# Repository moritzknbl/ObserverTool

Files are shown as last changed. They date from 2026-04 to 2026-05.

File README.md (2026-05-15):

# OpenCirclz - ObserverTool

A smart, pocket-sized timing and utility device for Roundnet observers, built on the ESP32 platform. It features timers for every situation with haptic feedback, a coin toss generator, seamless Scoreboard synchronization, and built-in OTA (Over-The-Air) update capabilities.

## ✨ Features
* **Smart Timers:** Pre-configured programs (Serve, Timeout, Break, Medicals) with visual countdowns.
* **Scoreboard Integration:** Wirelessly broadcasts active timers to the OpenCirclz Scoreboard via ESP-NOW for live stream or crowd overlays.
* **Haptic Feedback:** Custom vibration profiles for warnings, alarms, and interactions for a look-free interaction.
* **Power Management:** Auto-dimming and sleep modes for maximum battery life.
* **Coin Toss:** Built-in random heads/tails generator.
* **OTA & Web Hub:** Secret service mode to flash new firmware via Wi-Fi without a cable, and a Web Hub to configure hardware settings directly from your smartphone.
* **Easter Egg:** Hidden "Flappy Dot" mini-game.

## 🛠️ Hardware Requirements
* **Microcontroller:** ESP32-C3 Super Mini [HERE](https://de.aliexpress.com/item/1005008796274949.html)
* **Display:** 0.96" OLED I2C (128x64, SSD1306) [HERE](https://de.aliexpress.com/item/1005007084725556.html)
* **Inputs:** 2x Push Buttons (Start & Mode) (12*11mm opening size) [HERE](https://de.aliexpress.com/item/1005009402689922.html)
  *(Note: The software defaults to Normally Closed (NC) buttons, but Normally Open (NO) is fully supported and easily configurable via the Web Hub or local Settings Menu).*
* **Vibration:** QYF-740 Vibration Motor Module (Built-in driver, operates at 3.0-5.3VDC) [HERE](https://aliexpress.com/item/1005009127931477.html)
* **Battery:** Small 502030 3.7V LiPo Battery [HERE](https://de.aliexpress.com/item/1005006584143607.html)
* **Power Switch**: Simple ON/OFF Power Switch (19*13mm opening size) [HERE](https://aliexpress.com/item/1005008276122557.html)
* **Charge Controller:** Mini Type-C LiPo Charge/Discharge Module *(Specs: 18x12mm, 5V to 4.2V, set to 0.1A charge current, integrated over-discharge protection)* [HERE](https://de.aliexpress.com/item/1005010413122149.html)

### Pin Configuration
| Component | ESP32 Pin |
|---|---|
| I2C SCL (OLED) | GPIO 6 |
| I2C SDA (OLED) | GPIO 7 |
| START Button | GPIO 3 |
| MODE Button | GPIO 4 |
| Vibration Motor | GPIO 10 |

*(Note: Buttons are configured as `INPUT_PULLUP`, so connect them between the GPIO and GND).*

## 🧊 3D Printed Enclosure
To complete your ObserverTool, a custom-designed 3D printable case is available. You can find all the necessary `.stl` files directly in the [enclosure](enclosure) folder. 

**Assembly & Design:**
* **Highly Maintenance-Friendly:** The entire enclosure is designed without the need for any glue. 
* **Hardware:** Everything is assembled using **1.7 x 5 mm screws**.
* **Smart Mounting:** The OLED display, ESP32, and battery are securely held in place using custom 3D-printed pressure plates. This makes future repairs or battery replacements incredibly easy.

**Recommended Print Settings:**
* **Material:** PLA, PETG
* **Infill:** 15-20% is usually sufficient.

## 💻 Software Dependencies
To compile this project in the Arduino IDE or PlatformIO, you need the following libraries:
* `Adafruit GFX Library`
* `Adafruit SSD1306`

The ESP32 core libraries (`WiFi`, `esp_now`, `esp_wifi`, `WebServer`, `Update`, `DNSServer`, `Preferences`) are included by default in the ESP32 board package.

## 📥 Installation & Flashing Guide (Arduino IDE)

Follow these steps to compile and flash the firmware to your ESP32 for the first time:

### 1. Setup Arduino IDE & ESP32 Core
1. Download and install the latest [Arduino IDE](https://www.arduino.cc/en/software).
2. Open the IDE, go to **File > Preferences**, and paste the following URL into the *Additional Boards Manager URLs* field:
   `https://raw.githubusercontent.com/espressif/arduino-esp32/gh-pages/package_esp32_index.json`
3. Go to **Tools > Board > Boards Manager**, search for **esp32**, and install the package by *Espressif Systems*.

### 2. Install Required Libraries
Go to **Sketch > Include Library > Manage Libraries** and search for the following libraries to install them:
* `Adafruit GFX Library` (by Adafruit)
* `Adafruit SSD1306` (by Adafruit)

### 3. Configure Board Settings (⚠️ CRITICAL)
Connect your ESP32 to your computer via USB. Go to the **Tools** menu and configure the following settings:
* **Board:** Select your specific ESP32 board (e.g., `ESP32 Dev Module`, `ESP32C3 Dev Module`, etc.).
* **Partition Scheme:** Select **Minimal SPIFFS (1.9MB APP with OTA/128KB SPIFFS)**. 
  *(Note: This step is absolutely mandatory! If you skip this, the OTA-Update feature will not have enough memory to function and the board will crash).*
* **Port:** Select the COM port your ESP32 is connected to (e.g., `COM3` on Windows or `/dev/cu.usbserial-...` on Mac).

### 4. Flash the Firmware
1. Open the `ObserverTool.ino` file in the Arduino IDE.
2. Click the **Upload** button (the right-pointing arrow at the top left).
3. *Troubleshooting tip: If the IDE gets stuck at "Connecting...", press and hold the physical `BOOT` button on your ESP32 board until the flashing process starts.*

## 📦 Quick Update (Precompiled Binary)
If you already have a version of the ObserverTool running and just want to update to the latest firmware without compiling the code yourself, you can use the precompiled `.bin` file.

1. Go to the [Releases](../../releases) page of this repository.
2. Download the latest `ObserverTool_vX.X.bin` file from the "Assets" section.
3. Power on your ObserverTool while holding both the **Mode + Start** buttons to enter OTA Service Mode.
4. Connect to the Wi-Fi network `ObserverTool`.
5. Open your browser and navigate to `http://192.168.4.1` (or wait for the captive portal).
6. Upload the downloaded `.bin` file and hit "Flash Update". The device will restart automatically.

## 🚀 Usage & Controls
* **Normal Operation:**
  * Press **Mode** to cycle through the timer programs.
  * Press **Start** to start or stop the selected timer.
  * *Coin Toss:* Select "Coin Toss" and press Start to generate a random result.
* **Wake Up:** Press any button to wake the device from sleep or dim mode.

### Secret Boot Modes
Hold specific buttons **while powering on** the device to access special modes:
* **Settings Menu:** Hold `START`
  * Toggle **Scoreboard Sync** (ON/OFF) and **Button Type** (NC/NO) directly on the device.
* **OTA & Web Hub:** Hold `MODE` + `START`
  * Connect to the Wi-Fi AP `ObserverTool`.
  * A captive portal will appear (or navigate to `http://192.168.4.1`).
  * **Device Settings:** Configure your Button Type (NC/NO) and ESP-NOW Scoreboard Sync wirelessly via the browser.
  * **Update Firmware:** Upload your new `.bin` firmware file here.
* **Flappy Dot Game:** Hold `MODE`
  * Press `START` to jump. Press `MODE` to exit back to the main tool.

## 📄 License
This project is licensed under the Creative Commons Attribution-NC-SA 4.0 - see the [LICENSE](LICENSE) file for details.

**Personal Use Only:** You are free to build and use this project for yourself. 

**Non-Commercial:** You are NOT allowed to sell this project, the hardware, or the code. 
Commercial licenses are available upon request.

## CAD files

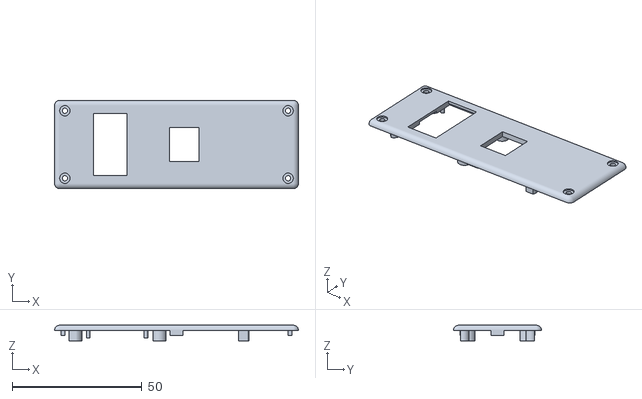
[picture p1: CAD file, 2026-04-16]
Hardware/ObserverTool_Top.stl
94.0 x 34.0 x 6.00

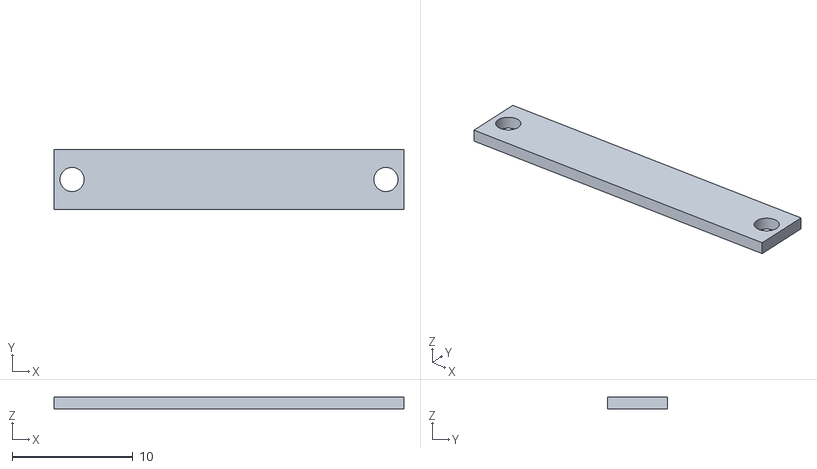
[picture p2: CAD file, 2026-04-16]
Hardware/Battery_Pressplate.stl
29.0 x 5.00 x 1.00

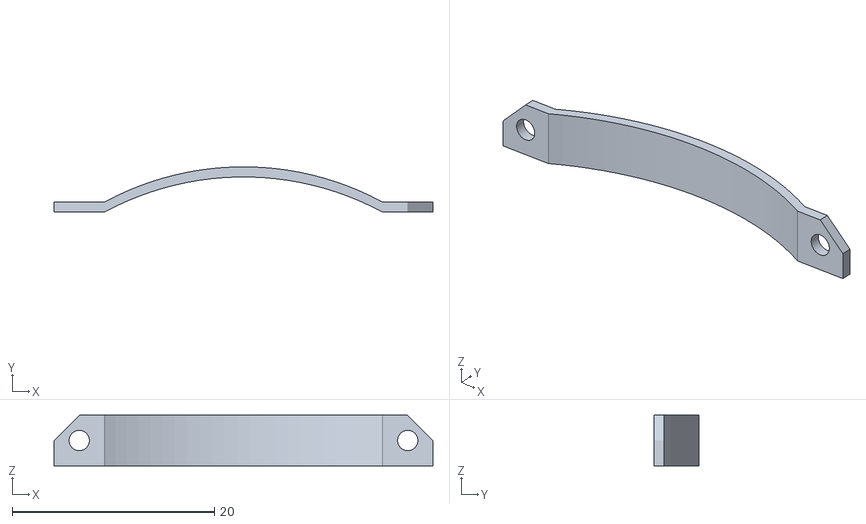
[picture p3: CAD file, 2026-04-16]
Hardware/Display_Pressplate_L.stl
37.5 x 4.47 x 5.00

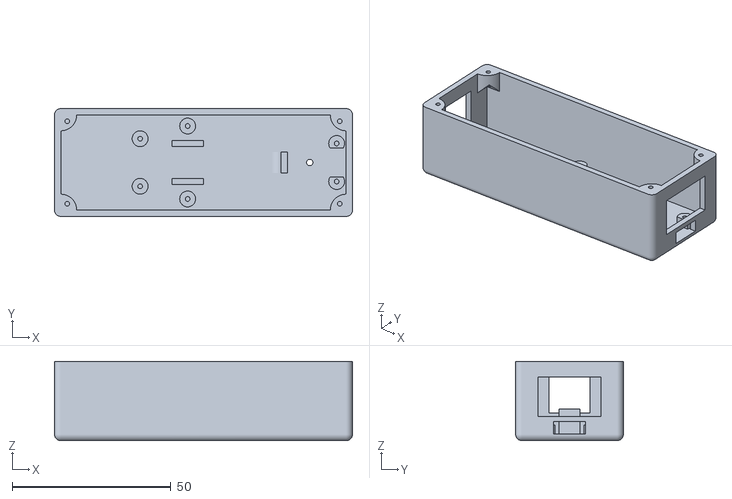
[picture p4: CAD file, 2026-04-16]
Hardware/ObserverTool_Body.stl
94.0 x 34.0 x 25.0

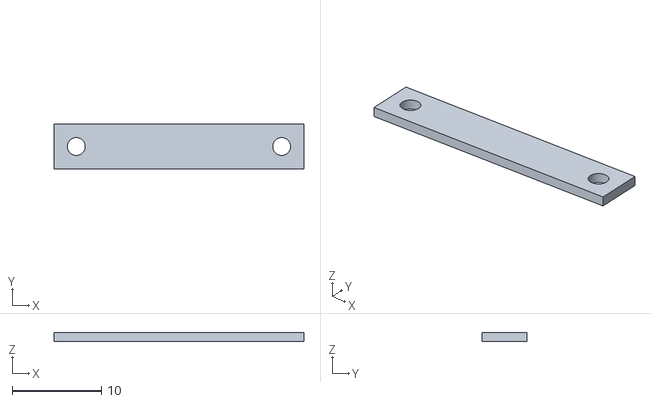
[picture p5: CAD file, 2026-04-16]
Hardware/ESP_Pressplate.stl
28.0 x 5.00 x 1.00

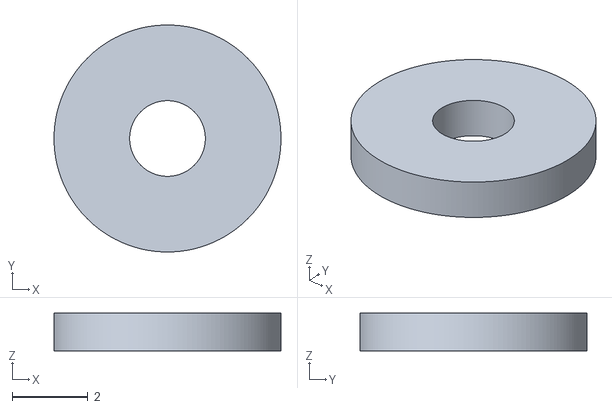
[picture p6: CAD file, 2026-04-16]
Hardware/Vibrationboard_Washer.stl
6.00 x 6.00 x 1.00

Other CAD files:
Hardware/Display_Pressplate_R.stl

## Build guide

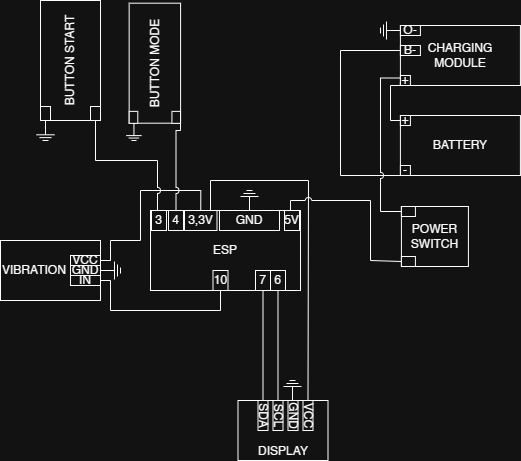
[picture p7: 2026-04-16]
Hardware/WiringDiagramm.jpg

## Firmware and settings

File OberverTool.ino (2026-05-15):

#include <Wire.h>
#include <Adafruit_GFX.h>
#include <Adafruit_SSD1306.h>
#include <Fonts/FreeSans18pt7b.h>
#include <Fonts/FreeSans24pt7b.h>
#include "esp_sleep.h" 
#include "esp_pm.h"
#include <WiFi.h>
#include <esp_now.h>   
#include <esp_wifi.h>  
#include <WebServer.h>
#include <Update.h>
#include <DNSServer.h>
#include <Preferences.h> 

// ==========================================
// --- CONFIGURATION ---
// ==========================================

// Pins
const int PIN_I2C_SCL = 6;
const int PIN_I2C_SDA = 7;
const int PIN_BTN_ACTION = 3;  
const int PIN_BTN_MODE = 4;    
const int PIN_VIB_MOTOR = 10;  

// Display
#define SCREEN_WIDTH 128
#define SCREEN_HEIGHT 64
#define OLED_RESET -1 
const uint8_t OLED_ADDRESS = 0x3C;

// Brightness levels (0-255)
const uint8_t BRIGHTNESS_HIGH = 207; 
const uint8_t BRIGHTNESS_DIM = 1;    

// Power saving mode (times in milliseconds)
const unsigned long DIM_TIMEOUT = 5 * 60 * 1000;    
const unsigned long SLEEP_TIMEOUT = 15 * 60 * 1000; 

// Hardware behavior (times in milliseconds)
const int DEBOUNCE_DELAY = 400; 

// Vibration profiles (duration in milliseconds)
const unsigned long VIB_BOOT_PULSE = 200;
const unsigned long VIB_BOOT_PAUSE = 150;
const unsigned long VIB_START = 200;
const unsigned long VIB_CANCEL = 150;
const unsigned long VIB_WARNING = 400;
const unsigned long VIB_ALARM_PULSE = 400;
const unsigned long VIB_ALARM_PAUSE = 0;
const int VIB_ALARM_COUNT = 1; 

// Boot screen duration
const unsigned long BOOT_DELAY_BEFORE_VIB = 1000;
const unsigned long BOOT_DELAY_AFTER_VIB = 1500;

// OTA Service Mode settings
const char* AP_SSID = "ObserverTool";
const char* FIRMWARE_VERSION = "v2.1"; 
const byte DNS_PORT = 53;

// Program definitions { "Name", Duration (ms), Warning (ms, 0 = off) }
struct Program {
  String name;                 
  unsigned long durationMs;    
  unsigned long warningMs;     
};

const int NUM_PROGRAMS = 7;
Program programs[NUM_PROGRAMS] = {
  {"Serve", 3000, 0},             
  {"Timeout", 60000, 20000},      
  {"Break", 180000, 60000},       
  {"1.Medical", 300000, 60000},   
  {"2.Medical", 60000, 20000},    
  {"3.Medical", 15000, 0},
  {"Coin Toss", 0, 0}             
};

// ==========================================
// --- GLOBAL VARIABLES ---
// ==========================================

Adafruit_SSD1306 display(SCREEN_WIDTH, SCREEN_HEIGHT, &Wire, OLED_RESET);
DNSServer dnsServer;
WebServer server(80);

int currentMenuIndex = 0;
bool isRunning = false;
unsigned long startTime = 0;
bool warningTriggered = false; 

unsigned long lastDebounceTime1 = 0;
unsigned long lastDebounceTime2 = 0;
unsigned long lastActivityTime = 0;
unsigned long vibrateUntil = 0;

bool isDimmed = false;

// ==========================================
// --- SYSTEM SETTINGS ---
// ==========================================
uint8_t broadcastAddress[] = {0xFF, 0xFF, 0xFF, 0xFF, 0xFF, 0xFF};
int scoreboardChannel = 1; 
bool espNowEnabled = true; 
bool isButtonNC = true; // True = Normally Closed (NC), False = Normally Open (NO)

typedef struct struct_message {
  bool start;
  unsigned long duration;
} struct_message;

// ==========================================
// --- FUNCTION DECLARATIONS ---
// ==========================================
bool isButtonPressed(int pin);
void runServiceMode();
void runFlappyBall();
void runCoinToss();
void openSettingsMenu(); 
void setDisplayBrightness(uint8_t contrast);
void drawHeader(String title);
void updateMenuDisplay();
void updateTimerDisplay(unsigned long remaining);
void triggerVibration(unsigned long duration);
void handleVibration(unsigned long currentMillis);
String getWebPage();
void setupESPNow();
void sendTimerCommand(bool start, unsigned long duration);

// ==========================================
// --- BUTTON LOGIC ABSTRACTION ---
// ==========================================
bool isButtonPressed(int pin) {
  if (isButtonNC) {
    return digitalRead(pin) == HIGH;
  } else {
    return digitalRead(pin) == LOW;
  }
}

// ==========================================
// --- SETUP ---
// ==========================================

void setup() {
  pinMode(PIN_BTN_ACTION, INPUT_PULLUP);
  pinMode(PIN_BTN_MODE, INPUT_PULLUP);
  pinMode(PIN_VIB_MOTOR, OUTPUT);
  digitalWrite(PIN_VIB_MOTOR, LOW);
  
  Wire.begin(PIN_I2C_SDA, PIN_I2C_SCL);
  if(!display.begin(SSD1306_SWITCHCAPVCC, OLED_ADDRESS)) {
    for(;;);
  }
  setDisplayBrightness(BRIGHTNESS_HIGH);

  display.clearDisplay();
  display.setTextSize(2);
  display.setTextColor(SSD1306_WHITE);
  display.setCursor(4, 1); 
  display.println("OpenCirclz");
  display.drawLine(0, 16, SCREEN_WIDTH, 16, SSD1306_WHITE);
  display.setCursor(16, 25);
  display.println("OBSERVER");
  display.setCursor(40, 45);
  display.println("TOOL");
  display.setTextSize(1);
  display.setCursor(0, 56);
  display.print(FIRMWARE_VERSION);
  display.display();

  Preferences prefsMain;
  prefsMain.begin("settings", true); 
  espNowEnabled = prefsMain.getBool("espnow", false); 
  scoreboardChannel = prefsMain.getInt("lastChan", 1); 
  isButtonNC = prefsMain.getBool("btnNC", true); 
  prefsMain.end();

  // --- BOOT MENU LOGIC ---
  if (isButtonPressed(PIN_BTN_MODE) && isButtonPressed(PIN_BTN_ACTION)) {
    runServiceMode(); 
  } 
  else if (isButtonPressed(PIN_BTN_MODE)) {
    runFlappyBall();  
  }
  else if (isButtonPressed(PIN_BTN_ACTION)) {
    openSettingsMenu(); 
  }

  if (espNowEnabled) {
    setupESPNow();
  }

  // Wakeup interrupts based on button type
  if (isButtonNC) {
    gpio_wakeup_enable((gpio_num_t)PIN_BTN_ACTION, GPIO_INTR_HIGH_LEVEL);
    gpio_wakeup_enable((gpio_num_t)PIN_BTN_MODE, GPIO_INTR_HIGH_LEVEL);
  } else {
    gpio_wakeup_enable((gpio_num_t)PIN_BTN_ACTION, GPIO_INTR_LOW_LEVEL);
    gpio_wakeup_enable((gpio_num_t)PIN_BTN_MODE, GPIO_INTR_LOW_LEVEL);
  }
  esp_sleep_enable_gpio_wakeup();
  
  delay(BOOT_DELAY_BEFORE_VIB); 
  digitalWrite(PIN_VIB_MOTOR, HIGH); delay(VIB_BOOT_PULSE);
  digitalWrite(PIN_VIB_MOTOR, LOW);  delay(VIB_BOOT_PAUSE);
  digitalWrite(PIN_VIB_MOTOR, HIGH); delay(VIB_BOOT_PULSE);
  digitalWrite(PIN_VIB_MOTOR, LOW);
  delay(BOOT_DELAY_AFTER_VIB); 
  
  updateMenuDisplay();
  lastActivityTime = millis(); 
}

// ==========================================
// --- MAIN LOOP ---
// ==========================================

void loop() {
  unsigned long currentMillis = millis();
  handleVibration(currentMillis); 

  bool actionPressed = isButtonPressed(PIN_BTN_ACTION);
  bool modePressed = isButtonPressed(PIN_BTN_MODE);

  if (isRunning) {
    lastActivityTime = currentMillis; 
  } else {
    unsigned long idleTime = currentMillis - lastActivityTime;
    if (idleTime >= SLEEP_TIMEOUT) {
      display.ssd1306_command(SSD1306_DISPLAYOFF); 
      esp_light_sleep_start(); 
      
      display.ssd1306_command(SSD1306_DISPLAYON); 
      setDisplayBrightness(BRIGHTNESS_HIGH);
      isDimmed = false;
      currentMillis = millis();
      lastActivityTime = currentMillis;
      lastDebounceTime1 = currentMillis + 500; 
      lastDebounceTime2 = currentMillis + 500;
      return; 
    } else if (idleTime >= DIM_TIMEOUT && !isDimmed) {
      setDisplayBrightness(BRIGHTNESS_DIM);
      isDimmed = true;
    }
  }

  if ((actionPressed || modePressed) && isDimmed) {
    setDisplayBrightness(BRIGHTNESS_HIGH);
    isDimmed = false;
    lastActivityTime = currentMillis;
    lastDebounceTime1 = currentMillis + 250;
    lastDebounceTime2 = currentMillis + 250;
  }

  // --- CANCEL BUTTON (MODE) ---
  if (modePressed && (currentMillis - lastDebounceTime2 > DEBOUNCE_DELAY) && !isDimmed) {
    lastActivityTime = currentMillis;
    if (!isRunning) {
      currentMenuIndex = (currentMenuIndex + 1) % NUM_PROGRAMS;
      updateMenuDisplay();
    } else {
      isRunning = false;
      triggerVibration(VIB_CANCEL); 

      Program p = programs[currentMenuIndex];
      if (p.name != "Serve" && p.name != "Coin Toss") {
        sendTimerCommand(false, 0);
      }
      
      currentMenuIndex = 0; 
      updateMenuDisplay();
    }
    lastDebounceTime2 = currentMillis;
  }

  // --- START BUTTON (ACTION) ---
  if (actionPressed && (currentMillis - lastDebounceTime1 > DEBOUNCE_DELAY) && !isDimmed) {
    lastActivityTime = currentMillis;
    if (!isRunning) {
      if (programs[currentMenuIndex].durationMs == 0) {
        runCoinToss();
        lastActivityTime = millis();
      } else {
        isRunning = true;
        startTime = currentMillis;
        warningTriggered = false; 
        triggerVibration(VIB_START);    
        
        Program p = programs[currentMenuIndex];
        if (p.name != "Serve" && p.name != "Coin Toss") {
          sendTimerCommand(true, p.durationMs);
        }
      }
    } else {
      if (currentMenuIndex == 0) { 
        startTime = currentMillis; 
        triggerVibration(VIB_START); 
      }
    }
    lastDebounceTime1 = currentMillis;
  }

  if (isRunning) {
    unsigned long elapsed = currentMillis - startTime;
    Program p = programs[currentMenuIndex];

    if (elapsed >= p.durationMs) {
      isRunning = false;

      if (p.name != "Serve" && p.name != "Coin Toss") {
        sendTimerCommand(false, 0);
      }

      display.clearDisplay();
      drawHeader(p.name);
      
      display.setFont(&FreeSans18pt7b);
      display.setTextSize(1);
      int16_t x1, y1;
      uint16_t w, h;
      display.getTextBounds("TIME", 0, 0, &x1, &y1, &w, &h);
      int xPos = (SCREEN_WIDTH - w) / 2 - x1;
      display.setCursor(xPos < 0 ? 0 : xPos, 50);
      display.println("TIME");
      display.setFont();
      display.display();

      for(int i = 0; i < VIB_ALARM_COUNT; i++) {
        digitalWrite(PIN_VIB_MOTOR, HIGH); delay(VIB_ALARM_PULSE); 
        digitalWrite(PIN_VIB_MOTOR, LOW);  if(i < VIB_ALARM_COUNT - 1) delay(VIB_ALARM_PAUSE); 
      }
      
      currentMenuIndex = 0; 
      updateMenuDisplay(); 
      lastActivityTime = millis(); 
    } else {
      unsigned long remaining = p.durationMs - elapsed;
      if (p.warningMs > 0 && !warningTriggered && remaining <= p.warningMs) {
        triggerVibration(VIB_WARNING); 
        warningTriggered = true;
      }
      updateTimerDisplay(remaining);
    }
  }
}

// ==========================================
// --- INTERACTIVE SETTINGS MENU ---
// ==========================================
void openSettingsMenu() {
  Preferences prefs;
  prefs.begin("settings", false); 
  
  while(isButtonPressed(PIN_BTN_ACTION)) { delay(10); } 

  bool inMenu = true;
  int menuPage = 0; // 0 = Sync, 1 = Button Type
  
  while (inMenu) {
    display.clearDisplay();
    drawHeader("SETTINGS");
    
    display.setTextSize(1);
    
    if (menuPage == 0) {
      String status1 = "Scoreboard Sync";
      int x1 = (SCREEN_WIDTH - (status1.length() * 6)) / 2;
      display.setCursor(x1 < 0 ? 0 : x1, 30);
      display.print(status1);

      display.setTextSize(2);
      String status2 = espNowEnabled ? "ON" : "OFF";
      int x2 = (SCREEN_WIDTH - (status2.length() * 12)) / 2;
      display.setCursor(x2 < 0 ? 0 : x2, 45);
      display.print(status2);
    } else {
      String status1 = "Button Type";
      int x1 = (SCREEN_WIDTH - (status1.length() * 6)) / 2;
      display.setCursor(x1 < 0 ? 0 : x1, 30);
      display.print(status1);

      display.setTextSize(2);
      String status2 = isButtonNC ? "NC" : "NO";
      int x2 = (SCREEN_WIDTH - (status2.length() * 12)) / 2;
      display.setCursor(x2 < 0 ? 0 : x2, 45);
      display.print(status2);
    }
    
    display.display();

    // Toggle Setting
    if (isButtonPressed(PIN_BTN_ACTION)) {
      if (menuPage == 0) {
        espNowEnabled = !espNowEnabled;
        prefs.putBool("espnow", espNowEnabled);
      } else {
        isButtonNC = !isButtonNC;
        prefs.putBool("btnNC", isButtonNC);
      }
      digitalWrite(PIN_VIB_MOTOR, HIGH); delay(50); digitalWrite(PIN_VIB_MOTOR, LOW); 
      
      while(isButtonPressed(PIN_BTN_ACTION)) { delay(10); }
    }

    // Next Page / Exit
    if (isButtonPressed(PIN_BTN_MODE)) {
      digitalWrite(PIN_VIB_MOTOR, HIGH); delay(150); digitalWrite(PIN_VIB_MOTOR, LOW);
      while(isButtonPressed(PIN_BTN_MODE)) { delay(10); }
      
      menuPage++;
      if (menuPage > 1) {
        inMenu = false; 
      }
    }
    
    delay(50);
  }
  
  prefs.end();
  display.clearDisplay();
  display.display();
}

// ==========================================
// --- ESP-NOW FUNCTIONS ---
// ==========================================
void setupESPNow() {
  WiFi.mode(WIFI_STA);
  
  bool found = false;
  int n = WiFi.scanNetworks(false, false, false, 120); 
  for (int i = 0; i < n; i++) {
    if (WiFi.SSID(i) == "Scoreboard") { 
      scoreboardChannel = WiFi.channel(i);
      found = true;
      
      Preferences prefs;
      prefs.begin("settings", false);
      prefs.putInt("lastChan", scoreboardChannel);
      prefs.end();
      break;
    }
  }
  WiFi.scanDelete();
  WiFi.mode(WIFI_OFF); 
}

void sendTimerCommand(bool start, unsigned long duration) {
  if (!espNowEnabled) return; 

  WiFi.mode(WIFI_STA);
  esp_wifi_set_promiscuous(true);
  esp_wifi_set_channel(scoreboardChannel, WIFI_SECOND_CHAN_NONE);
  esp_wifi_set_promiscuous(false);

  if (esp_now_init() == ESP_OK) {
    esp_now_peer_info_t peerInfo = {};
    memcpy(peerInfo.peer_addr, broadcastAddress, 6);
    peerInfo.channel = scoreboardChannel;
    peerInfo.encrypt = false;
    esp_now_add_peer(&peerInfo);

    struct_message msg;
    msg.start = start;
    msg.duration = duration;
    
    for(int i = 0; i < 10; i++) {
      esp_now_send(broadcastAddress, (uint8_t *) &msg, sizeof(msg));
      delay(10); 
    }
    
    esp_now_deinit();
  }
  
  WiFi.mode(WIFI_OFF); 
}

// ==========================================
// --- FEATURE: COIN TOSS ---
// ==========================================
void runCoinToss() {
  unsigned long tossStart = millis();
  int delayTime = 20;
  bool isHeads = false;

  while(millis() - tossStart < 2500) {
    isHeads = (esp_random() % 2 == 0); 
    
    display.clearDisplay();
    drawHeader("Coin Toss");
    
    display.setFont(&FreeSans18pt7b);
    display.setTextSize(1);
    String text = isHeads ? "HEADS" : "TAILS";
    int16_t x1, y1;
    uint16_t w, h;
    display.getTextBounds(text, 0, 0, &x1, &y1, &w, &h);
    int xPos = (SCREEN_WIDTH - w) / 2 - x1;
    display.setCursor(xPos < 0 ? 0 : xPos, 50);
    display.print(text);
    display.setFont();
    display.display();
    
    digitalWrite(PIN_VIB_MOTOR, HIGH); delay(15); digitalWrite(PIN_VIB_MOTOR, LOW);
    
    delay(delayTime);
    delayTime += 8; 
  }
  
  isHeads = (esp_random() % 2 == 0);
  
  display.clearDisplay();
  drawHeader("WINNER!");
  
  display.setFont(&FreeSans18pt7b);
  display.setTextSize(1);
  String text = isHeads ? "HEADS" : "TAILS";
  int16_t x1, y1;
  uint16_t w, h;
  display.getTextBounds(text, 0, 0, &x1, &y1, &w, &h);
  int xPos = (SCREEN_WIDTH - w) / 2 - x1;
  display.setCursor(xPos < 0 ? 0 : xPos, 50);
  display.print(text);
  display.setFont();
  display.display();
  
  digitalWrite(PIN_VIB_MOTOR, HIGH); delay(500); digitalWrite(PIN_VIB_MOTOR, LOW);
  delay(3000); 
  
  currentMenuIndex = 0; 
  updateMenuDisplay();
}

// ==========================================
// --- EASTEREGG: FLAPPY DOT ---
// ==========================================
void runFlappyBall() {
  Preferences prefs;
  prefs.begin("flappydot", false);
  int highscore = prefs.getInt("highscore", 0);

  while(isButtonPressed(PIN_BTN_ACTION) || isButtonPressed(PIN_BTN_MODE)) { delay(10); }

  display.clearDisplay();
  drawHeader("Flappy Dot");
  
  display.setTextSize(2);
  String hsStr = "RECORD: " + String(highscore);
  int hsX = (SCREEN_WIDTH - (hsStr.length() * 12)) / 2;
  display.setCursor(hsX < 0 ? 0 : hsX, 25);
  display.print(hsStr);

  display.setTextSize(1);
  String psStr = "- PRESS START -";
  int psX = (SCREEN_WIDTH - (psStr.length() * 6)) / 2;
  display.setCursor(psX < 0 ? 0 : psX, 50);
  display.print(psStr);
  
  display.display();

  while(true) {
    if(isButtonPressed(PIN_BTN_MODE)) { 
      prefs.end(); 
      return; 
    }
    if(isButtonPressed(PIN_BTN_ACTION)) break; 
    delay(10);
  }
  
  while(isButtonPressed(PIN_BTN_ACTION)) { delay(10); }

  float birdY = 32, birdVy = 0;
  int obsX = 128, obsW = 12, obsGap = 26, obsY = 32, score = 0;
  bool gameOver = false, lastBtnState = false;
  unsigned long lastFrame = 0;
  
  while(true) {
    if(millis() - lastFrame > 30) { 
      lastFrame = millis();
      
      if(!gameOver) {
        bool btnState = isButtonPressed(PIN_BTN_ACTION);
        if(btnState && !lastBtnState) {
          birdVy = -4.0; 
          digitalWrite(PIN_VIB_MOTOR, HIGH); delay(5); digitalWrite(PIN_VIB_MOTOR, LOW);
        }
        lastBtnState = btnState;
        
        birdVy += 0.5; 
        birdY += birdVy;
        obsX -= 3;     
        
        if(obsX < -obsW) {
          obsX = 128;
          obsY = (esp_random() % 34) + 15; 
          score++;
        }
        
        if(birdY + 3 >= 64 || birdY - 3 <= 0) gameOver = true;
        if(30 + 3 > obsX && 30 - 3 < obsX + obsW) { 
          if(birdY - 3 < obsY - obsGap/2 || birdY + 3 > obsY + obsGap/2) gameOver = true;
        }
        
        if(gameOver) {
          digitalWrite(PIN_VIB_MOTOR, HIGH); delay(400); digitalWrite(PIN_VIB_MOTOR, LOW);
          
          if (score > highscore) {
            highscore = score;
            prefs.putInt("highscore", highscore);
          }
        }
      } else {
        display.clearDisplay();
        drawHeader("GAME OVER");
        
        display.setTextSize(2);
        String scoreStr = "Score: " + String(score);
        int scX = (SCREEN_WIDTH - (scoreStr.length() * 12)) / 2;
        display.setCursor(scX < 0 ? 0 : scX, 25);
        display.print(scoreStr);
        
        display.setTextSize(1);
        String restStr = "- PRESS RESTART -";
        int restX = (SCREEN_WIDTH - (restStr.length() * 6)) / 2;
        display.setCursor(restX < 0 ? 0 : restX, 50);
        display.print(restStr);
        
        display.display();
        
        if(isButtonPressed(PIN_BTN_ACTION)) { 
          birdY = 32; birdVy = 0; obsX = 128; score = 0; gameOver = false;
          while(isButtonPressed(PIN_BTN_ACTION)) delay(10); 
        }
        if(isButtonPressed(PIN_BTN_MODE)) { 
          while(isButtonPressed(PIN_BTN_MODE)) delay(10);
          prefs.end();
          return; 
        }
        continue;
      }
      
      display.clearDisplay();
      display.setTextSize(1); display.setCursor(2, 2); display.print(score); 
      display.fillCircle(30, (int)birdY, 3, SSD1306_WHITE); 
      display.fillRect(obsX, 0, obsW, obsY - obsGap/2, SSD1306_WHITE); 
      display.fillRect(obsX, obsY + obsGap/2, obsW, 64 - (obsY + obsGap/2), SSD1306_WHITE); 
      display.display();
    }
  }
}

// ==========================================
// --- OTA SERVICE MODE ---
// ==========================================

const char web_page_html[] PROGMEM = R"rawliteral(
<!DOCTYPE html>
<html>
<head>
  <meta name='viewport' content='width=device-width, initial-scale=1'>
  <style>
    body{font-family:sans-serif;background:#222;color:#fff;text-align:center;padding:20px;}
    .card{background:#333;border-radius:8px;padding:20px;margin-bottom:20px;box-shadow:0 4px 8px rgba(0,0,0,0.2);}
    input[type=file]{margin-bottom:15px;padding:10px;background:#444;border-radius:5px;width:90%; color:#fff;}
    button, input[type=submit]{background:#f3ca20;color:#000;border:none;padding:12px 20px;font-size:16px;border-radius:5px;font-weight:bold;cursor:pointer;width:100%;max-width:300px;margin-top:10px;}
    .version{font-size:14px;color:#aaa;margin-bottom:20px;}
    select{padding:10px;font-size:16px;background:#444;color:#fff;border:none;border-radius:5px;width:100%;max-width:300px;margin-top:5px;}
    input[type=checkbox]{transform:scale(1.5);margin-right:10px;}
    label{font-size:16px;}
  </style>
</head>
<body>
  <h2>ObserverTool Hub</h2>
  <div class='version'>Current Version: <b>%VERSION%</b></div>

  <div class='card'>
    <h3>Device Settings</h3>
    <form method='POST' action='/savesettings'>
      <div style='text-align:left;max-width:300px;margin:0 auto;'>
        <p>
          <label><input type='checkbox' name='espnow' value='1' %ESPNOW_CHECKED%> Scoreboard Sync</label>
        </p>
        <p>
          <label>Button Type:</label><br>
          <select name='btnType'>
            <option value='NC' %BTN_NC_SEL%>Normally Closed (NC)</option>
            <option value='NO' %BTN_NO_SEL%>Normally Open (NO)</option>
          </select>
        </p>
      </div>
      <button type='submit'>Save Settings</button>
    </form>
  </div>

  <div class='card'>
    <h3>Firmware Update</h3>
    <form method='POST' action='/update' enctype='multipart/form-data'>
      <input type='file' name='update' accept='.bin'><br>
      <input type='submit' value='Flash Update'>
    </form>
  </div>

  <div class='card'>
    <form method='POST' action='/restart'>
      <button type='submit' style='background:#d9534f;color:#fff;'>Restart Device</button>
    </form>
  </div>
  
  <p style='color:#777;font-size:12px;'>&copy; OpenCirclz</p>
</body>
</html>
)rawliteral";

String getWebPage() {
  String html = String(web_page_html);
  html.replace("%VERSION%", FIRMWARE_VERSION); 
  html.replace("%ESPNOW_CHECKED%", espNowEnabled ? "checked" : "");
  html.replace("%BTN_NC_SEL%", isButtonNC ? "selected" : "");
  html.replace("%BTN_NO_SEL%", !isButtonNC ? "selected" : "");
  return html;
}
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

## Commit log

2026-04-16 Revise README for clarity and accuracy
    Updated product description and button names in README.
2026-04-16 Add initial ObserverTool functionality
    Initial implementation of ObserverTool with various features including display setup, vibration control, and OTA update functionality.
    [OberverTool.ino]
2026-04-16 Update README with installation and flashing instructions
    Added installation and flashing guide for ESP32 firmware.
2026-04-16 Revise hardware requirements and add enclosure details
    Updated hardware requirements and added 3D printed enclosure section with assembly details and recommended print settings.
2026-04-16 Update battery description in README.md
2026-05-15 Update firmware version and button logic
    Added option to set hardware button type (normally open/closed)
